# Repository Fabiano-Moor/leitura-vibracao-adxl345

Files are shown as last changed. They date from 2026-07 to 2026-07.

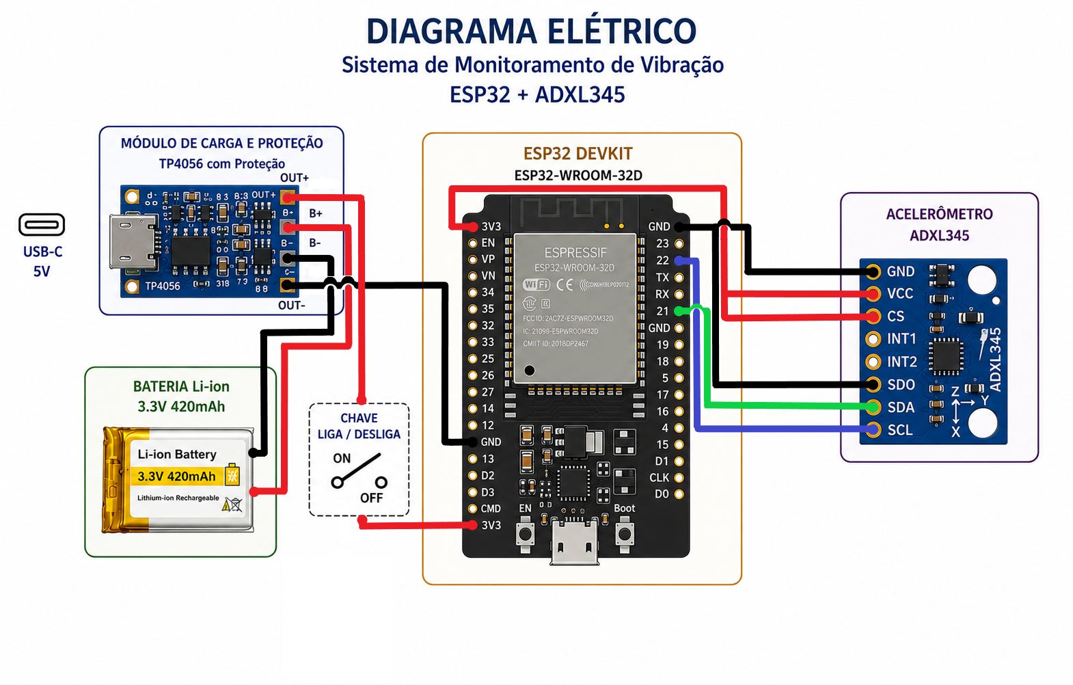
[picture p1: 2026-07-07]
eletrico.png

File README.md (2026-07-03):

# 📡 Leitura de Vibração e Frequência com ADXL345 + ESP32

Projeto acadêmico de monitoramento de vibração em equipamentos industriais/mecânicos utilizando o acelerômetro ADXL345 conectado a um ESP32, com interface web em tempo real acessível via Wi-Fi.

---

## 🎯 Objetivo

Medir a vibração de um equipamento e convertê-la em frequência (Hz), permitindo uma análise simplificada do estado do equipamento:

| Condição | Indicação |
|---|---|
| Frequência estável e baixa amplitude | ✅ Equipamento OK |
| Frequência elevada com amplitude alta | ⚠️ Possível desbalanceamento |
| Anomalia detectada pelo sistema | ❌ Verificar equipamento |

> **Nota:** Este projeto utiliza o ADXL345, um acelerômetro de baixo custo para fins acadêmicos. Para aplicações industriais reais, recomenda-se sensores de maior precisão.

---

## 🔧 Hardware necessário

- ESP32 (qualquer variante com Wi-Fi)
- Sensor ADXL345
- Jumpers para ligação
- Fonte de alimentação (USB ou externa 3.3V)

---

## 🔌 Ligações (modo I2C)

```
ESP32        →      ADXL345
─────────────────────────────
GND          →      GND
3.3V         →      VCC
3.3V         →      CS      (força modo I2C)
GND          →      SDO     (define endereço 0x53)
G21 (SDA)    →      SDA
G22 (SCL)    →      SCL
```

> ⚠️ **Atenção:** Não conecte ao 5V — o ADXL345 opera em 3.3V.

---

## 📚 Bibliotecas necessárias (Arduino IDE)

Instale pelo **Gerenciador de Bibliotecas** (`Sketch → Incluir Biblioteca → Gerenciar Bibliotecas`):

| `Adafruit ADXL345`        | Adafruit        |
| `Adafruit Unified Sensor` | Adafruit        |
| `arduinoFFT`              | kosme           |
| `WebSockets`              | Markus Sattler  |
| `ArduinoJson`             | Benoit Blanchon |  

---

## ⚙️ Configuração antes de usar

No início do código, altere as credenciais Wi-Fi para a sua rede:

```cpp
const char* ssid     = "NOME_DA_SUA_REDE";
const char* password = "SENHA_DA_SUA_REDE";
```

---

## 🚀 Como usar

### 1. Gravar o código
- Abra o arquivo `.ino` no Arduino IDE
- Selecione a placa: `ESP32 Dev Module`
- Grave o código no ESP32

### 2. Conectar ao Wi-Fi
- Abra o **Monitor Serial** (115200 baud)
- Aguarde a mensagem `Conectado!` e anote o IP exibido

### 3. Acessar a interface web
- No navegador, acesse: `http://IP_DO_ESP32`
- A interface exibe em tempo real:
  - Gráfico de vibração nos eixos X, Y e Z
  - Frequência dominante (Hz)
  - RMS e pico a pico da vibração
  - Espectro FFT
  - Log de anomalias

### 4. Calibrar o sensor
- Deixe o equipamento **parado e estável**
- Clique em **Calibrar** na interface
- Aguarde a calibração completar (~800 amostras)
- Após calibrado, o sistema passa a detectar anomalias automaticamente

### 5. Exportar dados
- Clique em **Baixar CSV** para exportar o histórico de leituras
- O arquivo contém: data/hora, operador, X, Y, Z, frequência, RMS e pico a pico

---

## 📊 Como interpretar os resultados

### Frequência dominante (Hz)
A FFT analisa o sinal de vibração e identifica a frequência com maior energia:

```
Frequência baixa  (<10 Hz)   → vibração lenta, estrutural
Frequência média  (10–50 Hz) → típico de motores elétricos comuns
Frequência alta   (>50 Hz)   → rotação elevada ou harmônicos
```

### RMS (Root Mean Square)
Representa a intensidade média da vibração:
- Valor baixo e estável → equipamento OK
- Valor crescente ao longo do tempo → desgaste ou desbalanceamento

### Detecção de anomalias (Z-Score)
O sistema aprende o comportamento normal do equipamento após a calibração e sinaliza quando o RMS se desvia mais de **3.5 desvios padrão** da média — indicando uma possível anomalia.

---

## 🧠 Funcionamento interno (resumo técnico)

```
Leitura bruta (800 Hz)
        ↓
Filtro anti-aliasing
        ↓
Filtro passa-alta  → remove gravidade/DC
        ↓
Filtro passa-baixa → suaviza ruído de alta frequência
        ↓
FFT (256 amostras) → identifica frequência dominante
        ↓
Interface Web (WebSocket) → atualização em tempo real
```

Os filtros se ajustam automaticamente com base na frequência dominante detectada, otimizando a leitura para o tipo de equipamento monitorado.

---

## 📁 Estrutura do repositório

```
📦 vibration-monitor-esp32
 ┣ 📄 adxl-esp32.ino        → firmware principal
 ┣ 📄 README.md             → este arquivo
 ┃ 📄 esquema.png        → diagrama de ligações
 | 📄 Fluxograma.png     → Fçuxograma
 ┃ 📄 caixa.stl          → modelo 3D da caixa
 ┃ 📄 artigo.pdf         → artigo completo

```

## 👥 Autores

Projeto acadêmico desenvolvido no curso de Engenharia Eletrônica — UNIENSINO.

- Clayton Duarte
- Fabiano Moor
- Mateus Alves
- Peterson Andrade

---

## ⚠️ Limitações

- O ADXL345 tem resolução de 10 bits e alcance máximo de ±16g — suficiente para análise acadêmica, mas limitado para diagnósticos industriais precisos
- A taxa de amostragem de 800 Hz permite detectar frequências de até 400 Hz (limite de Nyquist)
- A precisão da FFT depende da fixação física do sensor no equipamento — quanto melhor fixado, mais confiável a leitura
- O sistema requer Wi-Fi ativo para funcionamento da interface

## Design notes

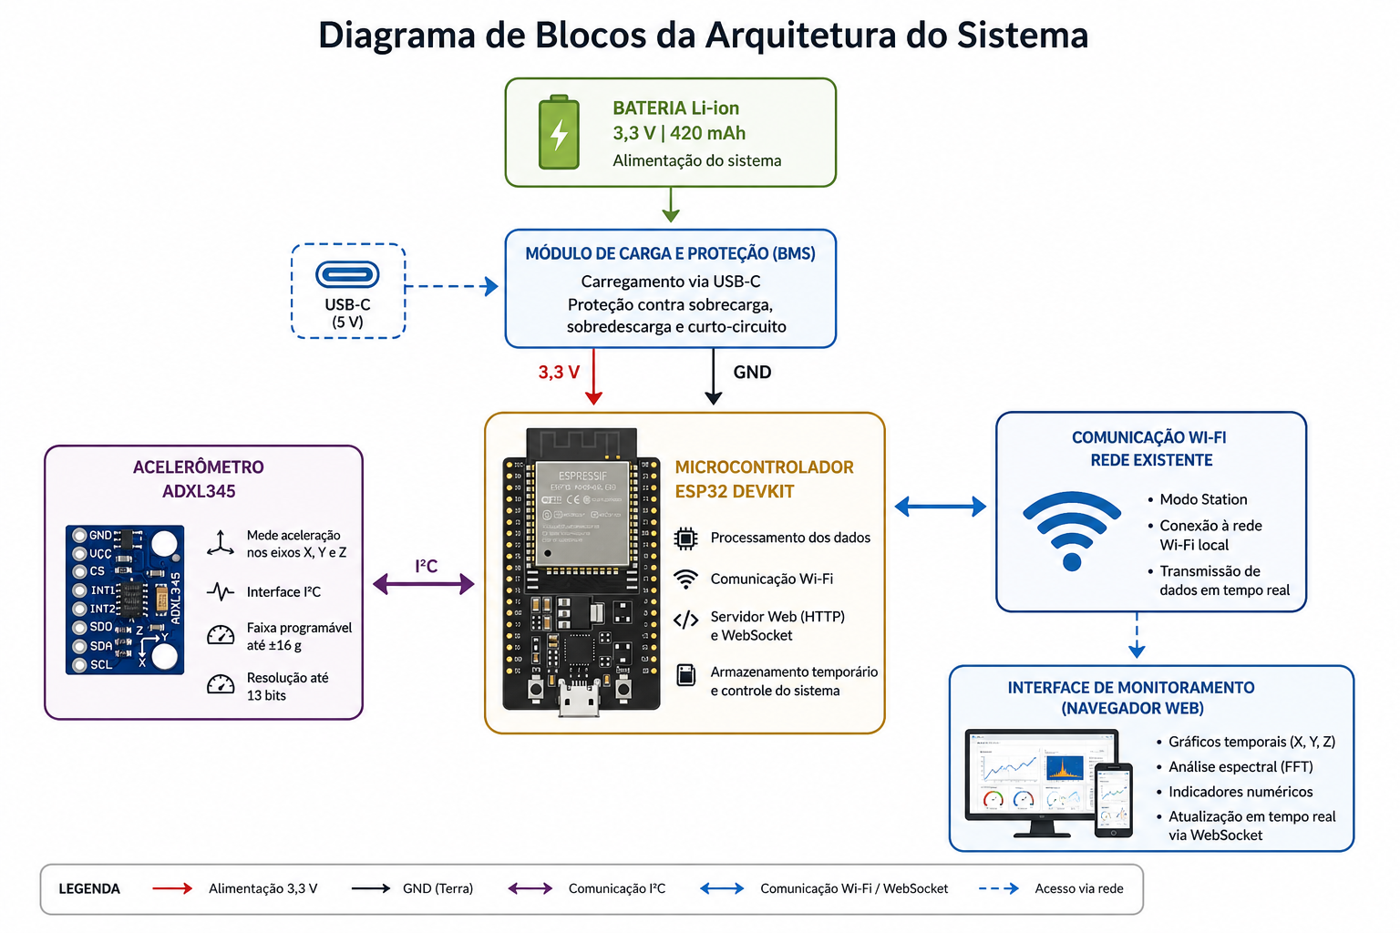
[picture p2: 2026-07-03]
Fluxograma.png

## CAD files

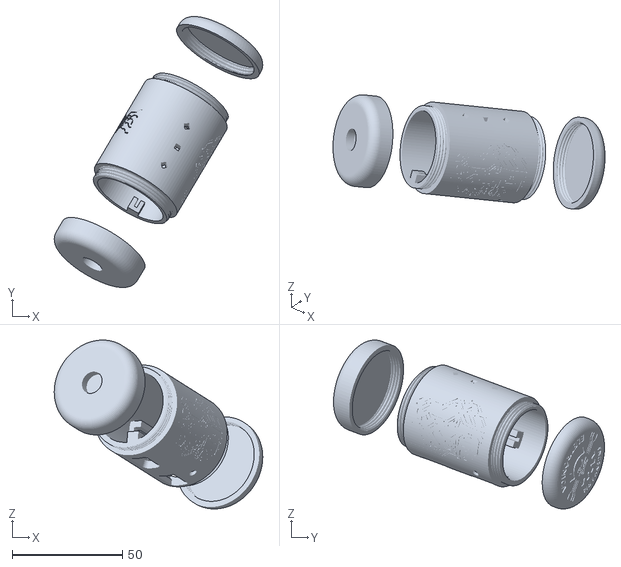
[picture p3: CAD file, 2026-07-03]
case sensor adxl redondo.stl
94.7 x 123.1 x 76.7

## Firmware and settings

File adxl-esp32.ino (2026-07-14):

// =============================================================================
// SISTEMA DE MONITORAMENTO DE VIBRACAO - VERSAO REVISADA
// Hardware: ESP32 / ESP32-C3 + ADXL345 por I2C
// Projeto : Engenharia Eletronica - UNIENSINO
// Autores : Clayton Duarte, Fabiano Moor, Mateus Alves, Peterson Andrade
// =============================================================================
//
// BIBLIOTECAS NECESSARIAS (Gerenciador de Bibliotecas da Arduino IDE):
//   - Adafruit ADXL345
//   - Adafruit Unified Sensor
//   - WebSockets by Markus Sattler
//   - arduinoFFT by Enrique Condes
//
// PINOS I2C:
//   ESP32 tradicional: SDA 21 / SCL 22
//   ESP32-C3: por padrao deste codigo SDA 8 / SCL 9
//   Altere I2C_SDA e I2C_SCL abaixo se sua placa usar outros pinos.
// =============================================================================

#include <WiFi.h>
#include <WebServer.h>
#include <WebSocketsServer.h>
#include <Wire.h>
#include <Adafruit_Sensor.h>
#include <Adafruit_ADXL345_U.h>
#include <arduinoFFT.h>
#include <time.h>

// =============================================================================
// CONFIGURACAO GERAL
// =============================================================================

const char* WIFI_SSID = "Fabiano D. Moor";
const char* WIFI_SENHA = "123456789";

#if defined(CONFIG_IDF_TARGET_ESP32C3)
constexpr int I2C_SDA = 8;
constexpr int I2C_SCL = 9;
#else
constexpr int I2C_SDA = 21;
constexpr int I2C_SCL = 22;
#endif

constexpr uint16_t TAM_BUFFER = 512;
constexpr uint16_t FFT_SAMPLES = 256;
constexpr uint16_t SAMPLING_FREQ = 400;
constexpr uint32_t PERIODO_AMOSTRA_US = 1000000UL / SAMPLING_FREQ;
constexpr uint16_t INTERVALO_ENVIO_MS = 50;   // 20 atualizacoes/s
constexpr uint16_t INTERVALO_FFT_MS = 500;    // FFT 2 vezes/s
constexpr uint8_t MAX_AMOSTRAS_PACOTE = 28;

constexpr float FREQUENCIA_MINIMA_HZ = 2.0f;
constexpr float FREQUENCIA_MAXIMA_HZ = 180.0f;
constexpr float FATOR_PICO_RUIDO = 5.0f;
constexpr float FC_PASSA_ALTA_HZ = 1.0f;
constexpr float GANHO_HAMMING = 0.54f;

static_assert((FFT_SAMPLES & (FFT_SAMPLES - 1)) == 0,
              "FFT_SAMPLES precisa ser potencia de 2");
static_assert(TAM_BUFFER >= FFT_SAMPLES,
              "TAM_BUFFER precisa ser maior ou igual a FFT_SAMPLES");

// =============================================================================
// OBJETOS PRINCIPAIS
// =============================================================================

WebServer server(80);
WebSocketsServer webSocket(81);
Adafruit_ADXL345_Unified accel(12345);

// =============================================================================
// BUFFER CIRCULAR E AQUISICAO
// =============================================================================

float bufferX[TAM_BUFFER];
float bufferY[TAM_BUFFER];
float bufferZ[TAM_BUFFER];
uint32_t bufferTempoUs[TAM_BUFFER];

volatile uint16_t indiceBuffer = 0;
volatile uint16_t amostrasValidas = 0;
volatile uint32_t totalAmostras = 0;
uint32_t totalAmostrasEnviadas = 0;

uint32_t proximaAmostraUs = 0;
uint32_t instanteInicialUs = 0;

// Estados do passa-alta digital fixo.
float hpX = 0.0f, hpY = 0.0f, hpZ = 0.0f;
float anteriorX = 0.0f, anteriorY = 0.0f, anteriorZ = 0.0f;
float alphaHP = 0.0f;

// =============================================================================
// CALIBRACAO DE REPOUSO
// =============================================================================

constexpr uint16_t AMOSTRAS_CALIBRACAO = 800; // 2 segundos em 400 Hz

bool calibrando = false;
bool calibrado = false;
uint16_t indiceCalibracao = 0;
uint32_t proximaCalibracaoUs = 0;

double somaCalX = 0.0, somaCalY = 0.0, somaCalZ = 0.0;
double somaQuadCalX = 0.0, somaQuadCalY = 0.0, somaQuadCalZ = 0.0;

float offsetX = 0.0f, offsetY = 0.0f, offsetZ = 0.0f;
float ruidoX = 0.0f, ruidoY = 0.0f, ruidoZ = 0.0f;
float limiarRmsRepouso = 0.09f;
float limiarPicoPicoRepouso = 0.35f;

// =============================================================================
// FFT E METRICAS
// =============================================================================

double vReal[FFT_SAMPLES];
double vImag[FFT_SAMPLES];
float espectroDb[FFT_SAMPLES / 2];
float espectroLinear[FFT_SAMPLES / 2];

ArduinoFFT<double> FFT(vReal, vImag, FFT_SAMPLES, SAMPLING_FREQ);

constexpr float RESOLUCAO_FFT = (float)SAMPLING_FREQ / FFT_SAMPLES;
constexpr float FREQUENCIA_NYQUIST = (float)SAMPLING_FREQ / 2.0f;

float rmsX = 0.0f, rmsY = 0.0f, rmsZ = 0.0f, rmsTotal = 0.0f;
float picoPicoX = 0.0f, picoPicoY = 0.0f, picoPicoZ = 0.0f;
float rmsEixo = 0.0f, picoPicoEixo = 0.0f;
float frequenciaDominante = 0.0f;
float magnitudeDominante = 0.0f;
float pisoRuidoEspectral = 0.0f;
char eixoAnalise = 'X';
char eixoManual = 'A'; // A = automatico; X/Y/Z = manual
bool sistemaEmRepouso = true;
bool fftAtualizada = false;

// =============================================================================
// BASELINE E EVENTOS
// =============================================================================

struct Evento {
  char dataHora[20];
  char operador[32];
  char tipo[20];
  float rms;
  float frequencia;
  float picoPico;
};

constexpr uint8_t MAX_EVENTOS = 30;
Evento eventos[MAX_EVENTOS];
uint32_t totalEventos = 0;
uint32_t ultimoEventoMs = 0;

char operadorAtual[32] = "Desconhecido";

float baselineRms = 0.0f;
float baselineVar = 0.0f;
uint16_t baselineAmostras = 0;
bool baselinePronto = false;
constexpr uint16_t BASELINE_WARMUP = 40;
constexpr float BASELINE_ALPHA = 0.025f;
constexpr float LIMIAR_ZSCORE = 3.5f;
constexpr uint32_t COOLDOWN_EVENTO_MS = 10000UL;
char diagnostico[20] = "REPOUSO";

// =============================================================================
// TEMPORIZACAO
// =============================================================================

uint32_t ultimoEnvioMs = 0;
uint32_t ultimaFftMs = 0;

// =============================================================================
// FUNCOES AUXILIARES
// =============================================================================

float quadrado(float valor) {
  return valor * valor;
}

void copiarTextoSeguro(char* destino, size_t tamanho, const String& origem) {
  if (tamanho == 0) return;
  origem.substring(0, tamanho - 1).toCharArray(destino, tamanho);
  destino[tamanho - 1] = '\0';
}

String timestampAtual() {
  struct tm infoTempo;
  if (!getLocalTime(&infoTempo, 20)) {
    return "--/--/---- --:--:--";
  }

  char texto[20];
  strftime(texto, sizeof(texto), "%d/%m/%Y %H:%M:%S", &infoTempo);
  return String(texto);
}

void zerarProcessamento() {
  hpX = hpY = hpZ = 0.0f;
  anteriorX = anteriorY = anteriorZ = 0.0f;

  indiceBuffer = 0;
  amostrasValidas = 0;
  totalAmostras = 0;
  totalAmostrasEnviadas = 0;

  for (uint16_t i = 0; i < TAM_BUFFER; i++) {
    bufferX[i] = 0.0f;
    bufferY[i] = 0.0f;
    bufferZ[i] = 0.0f;
    bufferTempoUs[i] = 0;
  }

  for (uint16_t i = 0; i < FFT_SAMPLES / 2; i++) {
    espectroDb[i] = -100.0f;
    espectroLinear[i] = 0.0f;
  }

  rmsX = rmsY = rmsZ = rmsTotal = 0.0f;
  picoPicoX = picoPicoY = picoPicoZ = 0.0f;
  rmsEixo = picoPicoEixo = 0.0f;
  frequenciaDominante = magnitudeDominante = 0.0f;
  pisoRuidoEspectral = 0.0f;
  sistemaEmRepouso = true;
  eixoAnalise = 'X';
  fftAtualizada = true;

  baselineRms = 0.0f;
  baselineVar = 0.0f;
  baselineAmostras = 0;
  baselinePronto = false;
  strncpy(diagnostico, "REPOUSO", sizeof(diagnostico));
  diagnostico[sizeof(diagnostico) - 1] = '\0';

  instanteInicialUs = micros();
  proximaAmostraUs = instanteInicialUs + PERIODO_AMOSTRA_US;
}

// =============================================================================
// CALIBRACAO
// =============================================================================

void iniciarCalibracao() {
  calibrando = true;
  calibrado = false;
  indiceCalibracao = 0;

  somaCalX = somaCalY = somaCalZ = 0.0;
  somaQuadCalX = somaQuadCalY = somaQuadCalZ = 0.0;

  proximaCalibracaoUs = micros();
  strncpy(diagnostico, "CALIBRANDO", sizeof(diagnostico));
  diagnostico[sizeof(diagnostico) - 1] = '\0';

  Serial.println("Calibracao iniciada. Mantenha o sensor totalmente parado.");
}

void finalizarCalibracao() {
  offsetX = somaCalX / AMOSTRAS_CALIBRACAO;
  offsetY = somaCalY / AMOSTRAS_CALIBRACAO;
  offsetZ = somaCalZ / AMOSTRAS_CALIBRACAO;

  const double varX = max(0.0, somaQuadCalX / AMOSTRAS_CALIBRACAO - quadrado(offsetX));
  const double varY = max(0.0, somaQuadCalY / AMOSTRAS_CALIBRACAO - quadrado(offsetY));
  const double varZ = max(0.0, somaQuadCalZ / AMOSTRAS_CALIBRACAO - quadrado(offsetZ));

  ruidoX = sqrt(varX);
  ruidoY = sqrt(varY);
  ruidoZ = sqrt(varZ);

  const float maiorRuido = max(ruidoX, max(ruidoY, ruidoZ));

  // Limiar de RMS e pico a pico calculados a partir do ruido medido.
  // Os limites inferiores evitam ficar no limite de um unico LSB do ADXL345.
  limiarRmsRepouso = constrain(maiorRuido * 3.5f, 0.07f, 0.30f);
  limiarPicoPicoRepouso = constrain(maiorRuido * 10.0f, 0.25f, 1.20f);

  calibrado = true;
  calibrando = false;
  zerarProcessamento();

  Serial.println("Calibracao concluida.");
  Serial.printf("Offsets: X=%.4f Y=%.4f Z=%.4f m/s2\n", offsetX, offsetY, offsetZ);
  Serial.printf("Ruido:   X=%.4f Y=%.4f Z=%.4f m/s2\n", ruidoX, ruidoY, ruidoZ);
  Serial.printf("Limiares: RMS=%.4f PP=%.4f m/s2\n",
                limiarRmsRepouso, limiarPicoPicoRepouso);
}

void tickCalibracao() {
  if (!calibrando) return;

  const uint32_t agoraUs = micros();
  if ((int32_t)(agoraUs - proximaCalibracaoUs) < 0) return;

  proximaCalibracaoUs += PERIODO_AMOSTRA_US;
  if ((int32_t)(agoraUs - proximaCalibracaoUs) > (int32_t)PERIODO_AMOSTRA_US) {
    proximaCalibracaoUs = agoraUs + PERIODO_AMOSTRA_US;
  }

  sensors_event_t evento;
  accel.getEvent(&evento);

  const float x = evento.acceleration.x;
  const float y = evento.acceleration.y;
  const float z = evento.acceleration.z;

  somaCalX += x;
  somaCalY += y;
  somaCalZ += z;
  somaQuadCalX += x * x;
  somaQuadCalY += y * y;
  somaQuadCalZ += z * z;
  indiceCalibracao++;

  if (indiceCalibracao >= AMOSTRAS_CALIBRACAO) {
    finalizarCalibracao();
  }
}

// =============================================================================
// AQUISICAO DO SENSOR
// =============================================================================

void adquirirAmostra() {
  sensors_event_t evento;
  accel.getEvent(&evento);

  // A calibracao remove a gravidade e os offsets para a posicao de montagem.
  const float xCorrigido = evento.acceleration.x - offsetX;
  const float yCorrigido = evento.acceleration.y - offsetY;
  const float zCorrigido = evento.acceleration.z - offsetZ;

  // Passa-alta fixo: remove deriva lenta sem alterar o filtro conforme a FFT.
  hpX = alphaHP * (hpX + xCorrigido - anteriorX);
  hpY = alphaHP * (hpY + yCorrigido - anteriorY);
  hpZ = alphaHP * (hpZ + zCorrigido - anteriorZ);

  anteriorX = xCorrigido;
  anteriorY = yCorrigido;
  anteriorZ = zCorrigido;

  const uint16_t posicao = indiceBuffer;
  bufferX[posicao] = hpX;
  bufferY[posicao] = hpY;
  bufferZ[posicao] = hpZ;
  bufferTempoUs[posicao] = micros() - instanteInicialUs;

  indiceBuffer = (posicao + 1) % TAM_BUFFER;
  if (amostrasValidas < TAM_BUFFER) amostrasValidas++;
  totalAmostras++;
}

void tickAquisicao() {
  if (calibrando || !calibrado) return;

  const uint32_t agoraUs = micros();
  if ((int32_t)(agoraUs - proximaAmostraUs) < 0) return;

  adquirirAmostra();
  proximaAmostraUs += PERIODO_AMOSTRA_US;

  // Nao le varias vezes em sequencia para "recuperar" atraso causado pela rede.
  if ((int32_t)(agoraUs - proximaAmostraUs) > (int32_t)PERIODO_AMOSTRA_US) {
    proximaAmostraUs = agoraUs + PERIODO_AMOSTRA_US;
  }
}

// =============================================================================
// EVENTOS E BASELINE
// =============================================================================

void registrarEvento(const char* tipo) {
  const uint32_t agora = millis();
  if (agora - ultimoEventoMs < COOLDOWN_EVENTO_MS) return;
  ultimoEventoMs = agora;

  const uint8_t indice = totalEventos % MAX_EVENTOS;
  copiarTextoSeguro(eventos[indice].dataHora,
                    sizeof(eventos[indice].dataHora),
                    timestampAtual());
  strncpy(eventos[indice].operador, operadorAtual,
          sizeof(eventos[indice].operador));
  eventos[indice].operador[sizeof(eventos[indice].operador) - 1] = '\0';
  strncpy(eventos[indice].tipo, tipo, sizeof(eventos[indice].tipo));
  eventos[indice].tipo[sizeof(eventos[indice].tipo) - 1] = '\0';
  eventos[indice].rms = rmsTotal;
  eventos[indice].frequencia = frequenciaDominante;
  eventos[indice].picoPico = picoPicoEixo;
  totalEventos++;
}

void atualizarBaseline() {
  if (!calibrado || sistemaEmRepouso) {
    strncpy(diagnostico, "REPOUSO", sizeof(diagnostico));
    diagnostico[sizeof(diagnostico) - 1] = '\0';
    return;
  }

  if (!baselinePronto) {
    baselineAmostras++;
    baselineRms += (rmsTotal - baselineRms) / baselineAmostras;

    strncpy(diagnostico, "APRENDENDO", sizeof(diagnostico));
    diagnostico[sizeof(diagnostico) - 1] = '\0';

    if (baselineAmostras >= BASELINE_WARMUP) {
      baselineVar = max(quadrado(baselineRms) * 0.0025f, 0.0001f);
      baselinePronto = true;
    }
    return;
  }

  const float diferenca = rmsTotal - baselineRms;
  const float sigma = sqrt(max(baselineVar, 0.000001f));
  const float zscore = fabs(diferenca) / sigma;

  if (zscore > LIMIAR_ZSCORE && diferenca > 0.0f) {
    strncpy(diagnostico, "ALERTA", sizeof(diagnostico));
    diagnostico[sizeof(diagnostico) - 1] = '\0';
    registrarEvento("ANOMALIA_RMS");

    // Uma anomalia nao e incorporada ao comportamento considerado normal.
    return;
  }

  strncpy(diagnostico, "NORMAL", sizeof(diagnostico));
  diagnostico[sizeof(diagnostico) - 1] = '\0';

  baselineVar = (1.0f - BASELINE_ALPHA) *
                (baselineVar + BASELINE_ALPHA * diferenca * diferenca);
  baselineRms = (1.0f - BASELINE_ALPHA) * baselineRms +
                BASELINE_ALPHA * rmsTotal;
}

// =============================================================================
// PROCESSAMENTO FFT
// =============================================================================

void zerarResultadoFft() {
  frequenciaDominante = 0.0f;
  magnitudeDominante = 0.0f;
  pisoRuidoEspectral = 0.0f;

  for (uint16_t i = 0; i < FFT_SAMPLES / 2; i++) {
    espectroLinear[i] = 0.0f;
    espectroDb[i] = -100.0f;
  }

  fftAtualizada = true;
}

void processarFFT() {
  if (amostrasValidas < FFT_SAMPLES || calibrando || !calibrado) {
    zerarResultadoFft();
    return;
  }

  double somaX = 0.0, somaY = 0.0, somaZ = 0.0;
  double somaQuadX = 0.0, somaQuadY = 0.0, somaQuadZ = 0.0;
  float minimoX = 1.0e9f, minimoY = 1.0e9f, minimoZ = 1.0e9f;
  float maximoX = -1.0e9f, maximoY = -1.0e9f, maximoZ = -1.0e9f;

  for (uint16_t i = 0; i < FFT_SAMPLES; i++) {
    const int indice = (indiceBuffer - FFT_SAMPLES + i + TAM_BUFFER) % TAM_BUFFER;
    const float x = bufferX[indice];
    const float y = bufferY[indice];
    const float z = bufferZ[indice];

    somaX += x;
    somaY += y;
    somaZ += z;
    somaQuadX += x * x;
    somaQuadY += y * y;
    somaQuadZ += z * z;

    if (x < minimoX) minimoX = x;
    if (x > maximoX) maximoX = x;
    if (y < minimoY) minimoY = y;
    if (y > maximoY) maximoY = y;
    if (z < minimoZ) minimoZ = z;
    if (z > maximoZ) maximoZ = z;
  }

  const float mediaX = somaX / FFT_SAMPLES;
  const float mediaY = somaY / FFT_SAMPLES;
  const float mediaZ = somaZ / FFT_SAMPLES;

  // RMS AC: a media residual e retirada matematicamente.
  rmsX = sqrt(max(0.0, somaQuadX / FFT_SAMPLES - mediaX * mediaX));
  rmsY = sqrt(max(0.0, somaQuadY / FFT_SAMPLES - mediaY * mediaY));
  rmsZ = sqrt(max(0.0, somaQuadZ / FFT_SAMPLES - mediaZ * mediaZ));
  rmsTotal = sqrt(quadrado(rmsX) + quadrado(rmsY) + quadrado(rmsZ));

  picoPicoX = maximoX - minimoX;
  picoPicoY = maximoY - minimoY;
  picoPicoZ = maximoZ - minimoZ;

  const float maiorRms = max(rmsX, max(rmsY, rmsZ));
  const float maiorPicoPico = max(picoPicoX, max(picoPicoY, picoPicoZ));

  // Histerese evita alternancia rapida entre repouso e vibracao.
  if (sistemaEmRepouso) {
    if (maiorRms > limiarRmsRepouso * 1.50f ||
        maiorPicoPico > limiarPicoPicoRepouso * 1.35f) {
      sistemaEmRepouso = false;
    }
  } else {
    if (maiorRms < limiarRmsRepouso &&
        maiorPicoPico < limiarPicoPicoRepouso) {
      sistemaEmRepouso = true;
    }
  }

  if (eixoManual == 'X' || eixoManual == 'Y' || eixoManual == 'Z') {
    eixoAnalise = eixoManual;
  } else if (rmsY > rmsX && rmsY >= rmsZ) {
    eixoAnalise = 'Y';
  } else if (rmsZ > rmsX && rmsZ > rmsY) {
    eixoAnalise = 'Z';
  } else {
    eixoAnalise = 'X';
  }

  if (eixoAnalise == 'X') {
    rmsEixo = rmsX;
    picoPicoEixo = picoPicoX;
  } else if (eixoAnalise == 'Y') {
    rmsEixo = rmsY;
    picoPicoEixo = picoPicoY;
  } else {
    rmsEixo = rmsZ;
    picoPicoEixo = picoPicoZ;
  }

  if (sistemaEmRepouso) {
    zerarResultadoFft();
    atualizarBaseline();
    return;
  }

  for (uint16_t i = 0; i < FFT_SAMPLES; i++) {
    const int indice = (indiceBuffer - FFT_SAMPLES + i + TAM_BUFFER) % TAM_BUFFER;

    if (eixoAnalise == 'X') {
      vReal[i] = bufferX[indice] - mediaX;
    } else if (eixoAnalise == 'Y') {
      vReal[i] = bufferY[indice] - mediaY;
    } else {
      vReal[i] = bufferZ[indice] - mediaZ;
    }
    vImag[i] = 0.0;
  }

  FFT.windowing(FFTWindow::Hamming, FFTDirection::Forward);
  FFT.compute(FFTDirection::Forward);
  FFT.complexToMagnitude();

  const uint16_t primeiroBin = max((int)1,
      (int)ceil(FREQUENCIA_MINIMA_HZ / RESOLUCAO_FFT));
  const uint16_t ultimoBin = min((int)(FFT_SAMPLES / 2 - 1),
      (int)floor(FREQUENCIA_MAXIMA_HZ / RESOLUCAO_FFT));

  float maiorMagnitude = 0.0f;
  uint16_t binDominante = 0;
  double somaSemMaior = 0.0;
  uint16_t quantidadeBins = 0;

  for (uint16_t i = 0; i < FFT_SAMPLES / 2; i++) {
    float magnitude = 0.0f;

    if (i > 0) {
      magnitude = (2.0f * (float)vReal[i]) /
                  (FFT_SAMPLES * GANHO_HAMMING);
    }

    espectroLinear[i] = magnitude;
    espectroDb[i] = 20.0f * log10(max(magnitude, 0.00001f));

    if (i >= primeiroBin && i <= ultimoBin) {
      somaSemMaior += magnitude;
      quantidadeBins++;

      if (magnitude > maiorMagnitude) {
        maiorMagnitude = magnitude;
        binDominante = i;
      }
    }
  }

  if (quantidadeBins > 1) {
    somaSemMaior -= maiorMagnitude;
    pisoRuidoEspectral = somaSemMaior / (quantidadeBins - 1);
  } else {
    pisoRuidoEspectral = 0.0f;
  }

  const bool picoConfiavel =
      maiorMagnitude > 0.0f &&
      maiorMagnitude >= max(0.005f, pisoRuidoEspectral * FATOR_PICO_RUIDO) &&
      rmsEixo >= limiarRmsRepouso;

  if (picoConfiavel) {
    float deslocamentoBin = 0.0f;

    // Interpolacao parabolica melhora a frequencia entre dois bins.
    if (binDominante > 0 && binDominante < FFT_SAMPLES / 2 - 1) {
      const float esquerda = espectroLinear[binDominante - 1];
      const float centro = espectroLinear[binDominante];
      const float direita = espectroLinear[binDominante + 1];
      const float denominador = esquerda - 2.0f * centro + direita;

      if (fabs(denominador) > 1.0e-9f) {
        deslocamentoBin = 0.5f * (esquerda - direita) / denominador;
        deslocamentoBin = constrain(deslocamentoBin, -0.5f, 0.5f);
      }
    }

    frequenciaDominante = (binDominante + deslocamentoBin) * RESOLUCAO_FFT;
    magnitudeDominante = maiorMagnitude;
  } else {
    frequenciaDominante = 0.0f;
    magnitudeDominante = 0.0f;
  }

  atualizarBaseline();
  fftAtualizada = true;
}

// =============================================================================
// JSON E WEBSOCKET
// =============================================================================

void adicionarArrayBuffer(String& json,
                          const char* nome,
                          const float* buffer,
                          uint32_t primeiraSequencia,
                          uint8_t quantidade,
                          bool virgulaDepois) {
  json += '\"';
  json += nome;
  json += "\":[";

  for (uint8_t i = 0; i < quantidade; i++) {
    const uint32_t sequencia = primeiraSequencia + i;
    const uint32_t idade = totalAmostras - sequencia;
    const int indice = (indiceBuffer - (int)idade + TAM_BUFFER) % TAM_BUFFER;

    json += String(buffer[indice], 3);
    if (i + 1 < quantidade) json += ',';
  }

  json += ']';
  if (virgulaDepois) json += ',';
}
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
void loop() {
  // A aquisicao/calibracao vem antes das tarefas de rede.
  if (calibrando) tickCalibracao();
  else tickAquisicao();

  webSocket.loop();
  server.handleClient();

  const uint32_t agoraMs = millis();

  if (!calibrando && calibrado &&
      agoraMs - ultimaFftMs >= INTERVALO_FFT_MS) {
    ultimaFftMs = agoraMs;
    processarFFT();
  }

  if (agoraMs - ultimoEnvioMs >= INTERVALO_ENVIO_MS) {
    ultimoEnvioMs = agoraMs;
    enviarIncremental();
  }
}

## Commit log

2026-05-13 Update adxl-esp32.ino
    otimizado o código e descrição de cada parte.
2026-07-03 Add files via upload
    Case do projeto adxl + esp32, para monitoramento de vibração.
    [case sensor adxl redondo.stl]
2026-07-03 Add files via upload
    Esquema de ligação
